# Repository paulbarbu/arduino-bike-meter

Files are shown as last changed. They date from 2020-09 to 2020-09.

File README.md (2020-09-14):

Bike-Meter
==========
Note: work in progress

A simple speed and distance bike computer built on Arduino Nano, showing the data on a 16x2 LCD display, featuring automatic display brightness adjustment.

If you're using your bike on a home trainer and don't have the necessary speed sensors on it, this might help.
It uses a hall sensor connected to the Arduino Nanoa to count your back wheel's rotations and from there it computes the speed and distance
traveled for the current training session.

So you need to place the hall sensor near the roller of your home trainer and using long enough wires, place the arduino and
the LCD display near the cockpit of the bike.
You'll also need to attach a magnet to your home trainer's roller and near the afore mentioned hall sensor.

*NOTE:* Make sure nothing will get stuck to your wheel, cables and such. Do not damage your equipment or yourself.

Usage
=====
You may need to change the `WHEEL_DIAMETER` to reflect you wheel's diameter in millimeters for accurate computations.
Do the same for `TRAINER_ROLLER_DIAMETER`.

If no rotations are detected, you need to decrease the distance between the magnet and the hall sensor.

Flash on the arduino, attach to trainer and power the arduino.
There is no start/stop button, nor does it store the data computed during the training session.
From the power-up moment, the arduino starts doing its job.

In order to avoid keeping your laptop near the bike after flashing the arduino, you may power the arduino from a power bank or using the pins dedicated to an external power supply.

Parts
=====
* Arduino Nano
* TLE4906L Hall effect sensor
* 16x2 LCD
* LCM 1602 I2C module for the 16x2 LCD
* 1x 220 Ohm resistor
* 2x 10 kOhm resistors
* Phototresistor
* LM35 temperature sensor

Wiring details can be found in the code itself and in the image below:
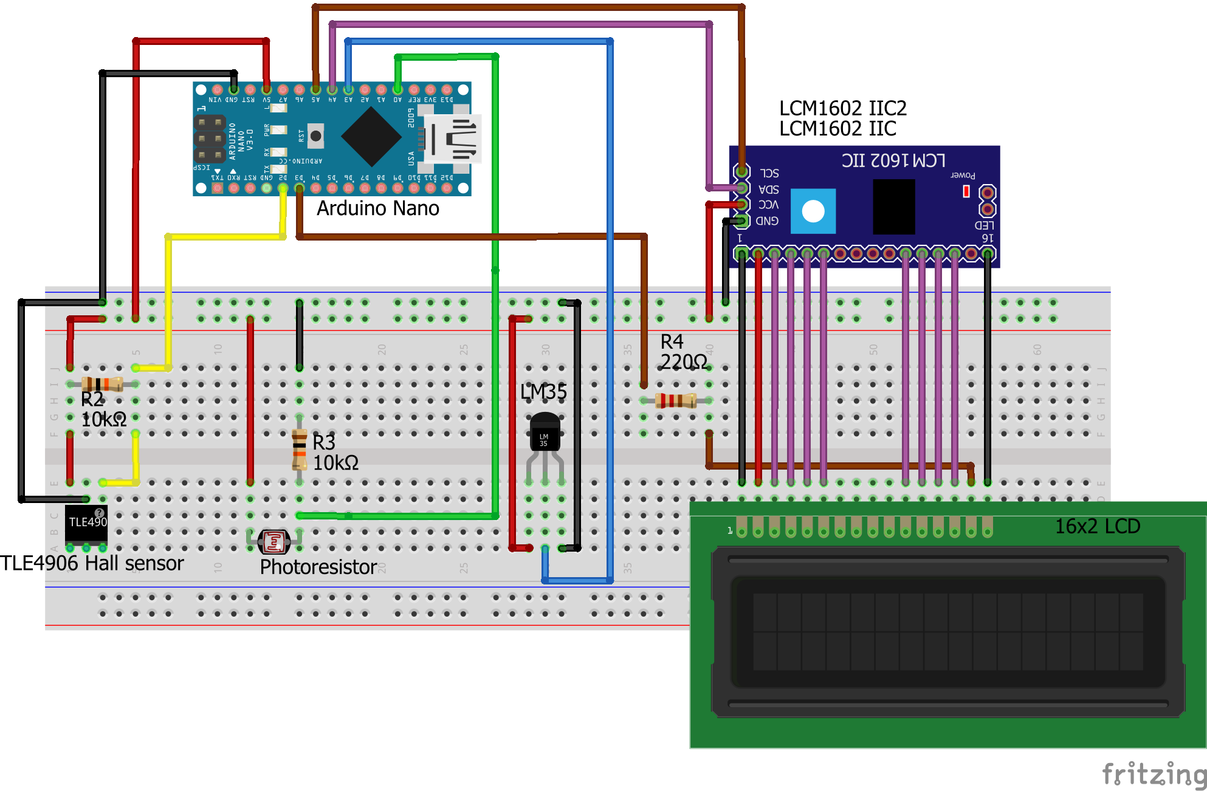
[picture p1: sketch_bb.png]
sketch_bb.png - Parts wiring details Wiring details


LICENSE
=======
See the LICENSE file (MIT).

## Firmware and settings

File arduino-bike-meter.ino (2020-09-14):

#include <LiquidCrystal_I2C.h>

//#define DEBUG

// https://www.makerguides.com/character-i2c-lcd-arduino-tutorial/
// Download: https://gitlab.com/tandembyte/LCD_I2C/

// 16x2 LCD connections:
// VCC - 5V
// GNC - GND
// SDA - A4
// SCL - A5

// Hall sensor connections:
// digital out of hall sensor to D2 of arduino
int interruptPin = 2; //D2, digital input, internal pull up (from TLE4906L Hall effect sensor's output pin)

int photoresistorPin = A0; //A0, analog input (from photoresistor)
int pwmLedPin = 3; //D3, PWM, output (to the 16x2 LCD's anode)
int tempPin = A3; //A3, analog input (from LM35 temp sensor)

const int TRAINER_ROLLER_DIAMETER = 50; // mm
const int WHEEL_DIAMETER = 700; // mm
const float REDUCTION = (float) WHEEL_DIAMETER / (float) TRAINER_ROLLER_DIAMETER; // for every REDUCTION rotations of the trainer's roller the bike's wheel spins once
const float WHEEL_CIRCUMFERENCE = PI * WHEEL_DIAMETER / 1000.0 / 1000.0; // km

LiquidCrystal_I2C lcd(0x3F, 16, 2); // use I2C scanner to find the address
const char bell[8] PROGMEM = {B00100, B01110, B01110, B01110, B11111, B00000, B00100, B00000};

volatile unsigned long num_rotations = 0;
unsigned long last_compute_time = 0; // last time we computed the stats
unsigned long last_num_rotations = 0;
float max_speed = 0; // km/h

unsigned long last_light_time = 0; // last time we updated the LCD's light intensity

const long LIGHT_DIM_THRESHOLD = 100; // [ms] - how often we shuld read the photoresistor and update the LCD's brightness

const long SECOND = 1000;
const long MINUTE = 60 * SECOND;
const long HOUR = 60 * MINUTE;

// the number of readings of the temp is equal to the times we update the light on the LCD
// since we read the temp and update the light at the same time
const int numTemps = SECOND/LIGHT_DIM_THRESHOLD;
int rawTemps[numTemps]; // the vector where we will store the last numTemps temperature readings
int currentTempPos = 0; // position where we should write the next temperature reading
int rawTotalTemp = 0; // the running average will be computed from this total



void countRotations()
{
  num_rotations++;
}

void setup()
{
#ifdef DEBUG
  Serial.begin(9600);
#endif

  pinMode(interruptPin, INPUT_PULLUP);
  attachInterrupt(digitalPinToInterrupt(interruptPin), countRotations, FALLING); //normal output = 5V, when magnet is near, output = 0V.
  lcd.init();
  lcd.backlight();

  lcd.createChar(0, bell);

  for(int i=0; i<numTemps; ++i)
  {
    rawTemps[i] = 0;
  }
}

void loop() {
  unsigned long current_time = millis();
  unsigned long time_diff = current_time - last_compute_time;
  unsigned long light_time_diff = current_time - last_light_time;

  if (time_diff >= SECOND)
  {
    last_compute_time = current_time;
    // count the trainer's roller number of rotations and from there compute the bike's wheel number of rotations
    unsigned long rots_in_period = num_rotations - last_num_rotations;
    last_num_rotations = num_rotations;

    float bike_rotations = num_rotations / REDUCTION;
    float bike_rots_in_period = rots_in_period / REDUCTION;
    

    //lcd.clear(); //TODO: write the whole screen  in order to avoid this flicker
    lcd.home();
    //lcd.print("Rots ");
    //lcd.print(num_rotations);

    float distance = WHEEL_CIRCUMFERENCE * bike_rotations; // km
    float dist_per_time_unit = distance / current_time; // km/ms
    float avg_speed = dist_per_time_unit * HOUR; // km/h
    // try avg_spd = (dst*HOUR)/current_time;
    
    float instant_distance = WHEEL_CIRCUMFERENCE * bike_rots_in_period; // km

    //knowing that the update period is 1 second (time diff) I could transform this to: instant_distance * 60*60;
    float instant_speed = (instant_distance / time_diff) * HOUR; // km/h

    if(instant_speed > max_speed)
    {
        max_speed = instant_speed;
    }
    
    // do these computations only when showing them to the user since they are expensive
    float rawAvgTemp = rawTotalTemp/numTemps;
    float tempMilliVolts = rawAvgTemp/1024.0 * 5000.0; // transform to millivolts

    float tempC = tempMilliVolts/10; // every 10mV are 1 deg C

#ifdef DEBUG
    Serial.print("WHEEL_DIAMETER: ");
    Serial.println(WHEEL_DIAMETER);

    Serial.print("WHEEL_CIRCUMFERENCE: ");
    Serial.println(WHEEL_CIRCUMFERENCE);

    Serial.print("SECOND: ");
    Serial.println(SECOND);

    Serial.print("MINUTE: ");
    Serial.println(MINUTE);

    Serial.print("HOUR: ");
    Serial.println(HOUR);

    Serial.print("Total rotations: ");
    Serial.println(num_rotations);

    Serial.print("Total bike rotations: ");
    Serial.println(bike_rotations);

    Serial.print("Total Distance [km]: ");
    Serial.println(distance, 4);

    Serial.print("Average Speed [km/h]: ");
    Serial.println(avg_speed, 4);

    Serial.print("Dist per time unit [km/ms]: ");
    Serial.println(dist_per_time_unit, 4);

    Serial.print("Current time [s]: ");
    Serial.println((float)current_time / SECOND, 4);

    Serial.print("time diff: ");
    Serial.println(time_diff);

    Serial.print("rotations in period: ");
    Serial.println(rots_in_period);

    Serial.print("Bike rotations in period: ");
    Serial.println(bike_rots_in_period);

    Serial.print("Instant distance [km]: ");
    Serial.println(instant_distance, 4);

    Serial.print("Instant speed [km/h]: ");
    Serial.println(instant_speed, 4);
    
    Serial.print("Max speed [km/h]: ");
    Serial.println(max_speed, 4);
    
    Serial.print("Temp [deg C]: ");
    Serial.println(tempC, 4);

    Serial.println();
#endif

    lcd.print("A "); //2 chars used
    lcd.print(avg_speed, 2); //+5 = 7 chars used
    lcd.print(" M "); //+3 = 10 chars used
    lcd.print(max_speed, 2); //+5 = 15 chars used
    lcd.print("           "); // make sure left over charachters on the line are overwritten

    lcd.setCursor(0, 1); // col, line
    lcd.print("S "); 
    lcd.print(instant_speed, 2); //+5 = 7 chars used
    lcd.print(" D "); //+3 = 10 chars used
    lcd.print(distance, 2); //+5 or 6 = 15/16 chars used
    lcd.print("           "); // make sure left over charachters on the line are overwritten


    //TODO: show this only if the user pressed a button:
    lcd.setCursor(0, 0); // col, line
    lcd.print("Temp "); 
    lcd.print(tempC, 2); //+5 or 6 = 15/16 chars used
    lcd.print(" C          "); // make sure left over charachters on the line are overwritten


    //TODO: show the user the temp and the temp with the windchill
    
    //lcd.write(0); //bell
  }

  // only update the display's light intensity every LIGHT_DIM_THRESHOLD ms
  // we also do the temp readings here
  if(light_time_diff >= LIGHT_DIM_THRESHOLD)
  {
    last_light_time = current_time;
    int lightAmount = analogRead(photoresistorPin);
    
    // get how much light hits the photoresistor (0-1023) and map that value to 0-255 in order to be able to change the intensity of the LCD's LED.
    // only we do the mapping inversely: when we have a big amount of light hitting the photoresistor, we want to turn off the LED, so 1023 -> 0
    // and when we have a small amount of light hitting the photoresistor (night), we want to turn on the LED, so 0 -> 255.
    int mappedLightAmount = map(lightAmount, 0, 1023, 255, 0);

    // update the LCD's brightness
    analogWrite(pwmLedPin, mappedLightAmount);

    // before overwriting the temperature with the latest one, subtract the stale value from the total
    rawTotalTemp -= rawTemps[currentTempPos];

    // read the temperature
    int rawTemp = analogRead(tempPin); // 0 - 1023;

    // update the temperatures and the total
    rawTemps[currentTempPos] = rawTemp;
    rawTotalTemp += rawTemp;
    
    currentTempPos += 1;
    currentTempPos %= numTemps; // make sure we go to the beginning of the vector
  }
}

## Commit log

2020-09-12 basic bike mater based on arduino nano
2020-09-14 added Fritzing sketch showing the connections
    [sketch.fzz]
2020-09-14 Added wiring details and needed parts for the automatic brightness adjustment
2020-09-14 added the TLE4096L datasheet - the centerpiece of this project - apart from the Arduino
2020-09-14 added LM35 based temperature reading - display a running average
    [sketch.fzz]
